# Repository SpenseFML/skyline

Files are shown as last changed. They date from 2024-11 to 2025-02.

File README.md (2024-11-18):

# Skyline
Hello everyone, 
I'm really glad that you are here, reading about my new Keyboard.
The Skyline is a 34 key wireless split keyboard with a slight angle and curved layout and agressive pinky stagger.

In total you have 4 choices what to build:
With(out) display 
With(out) hotswap sockets

If you want to mix and match, the world is your oyster, just print what you need, every version has files for both sides. Just look at the prints and pictures to see what is in your budget and what is usefull for you :)

## The whats and whys
This isn't my first self-designed keyboard and I hope it isn't my last. 
My self-build collection consists of:
Lowbro (a plancklike self printed and designed low profile)
Reviung41
Corne (with displays)
Skeletyl (self printed)
dove36 (fusion of the reviung41 and skeletyl, self designed)

The Skyline is the product of all the experiences I made building, designing and using these keyboards.
I wanted a Keyboard, that only has the number of keys (34) that I needed for my day to day work with it and it should look like something new and unique. Also I wanted to use displays in a self-built keyboard, to see how it's done and to make it more fancy :D (it looks cool, but it's not really necessary tbh)
Another important aspect for me is that I just wanted the challenge of finishing a project, that isn't just "print this file from the internet and solder some switches to a controller" and releasing it as a somewhat polished and usable product for the keyboard community to build and have fun with.

## Building the Skyline
Building your own mechanical keyboard can be a fun and very fulfilling experience. 
It can also be very demanding and hard, because you can run into problems and do mistakes, which will set you back and make you start over. 
Don't get discouraged.
Every build is a chance to learn and get better!
I wrote a [build guide](buildguide/BUILDGUIDE.md) for the Skyline with some tips and tricks to help you in the building process. If you still need help or have questions (or want to see other designs) feel free to join my [discord server](https://discord.gg/6NYX3pecrV) and just ask me directly, I'll help as much as I can :)

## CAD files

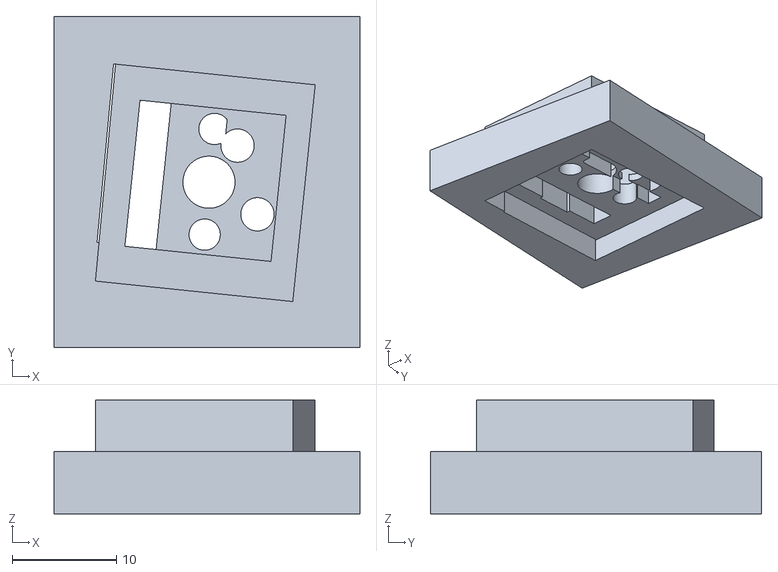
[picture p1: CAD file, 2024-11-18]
stls/print_helper.stl
29.3 x 31.8 x 10.9

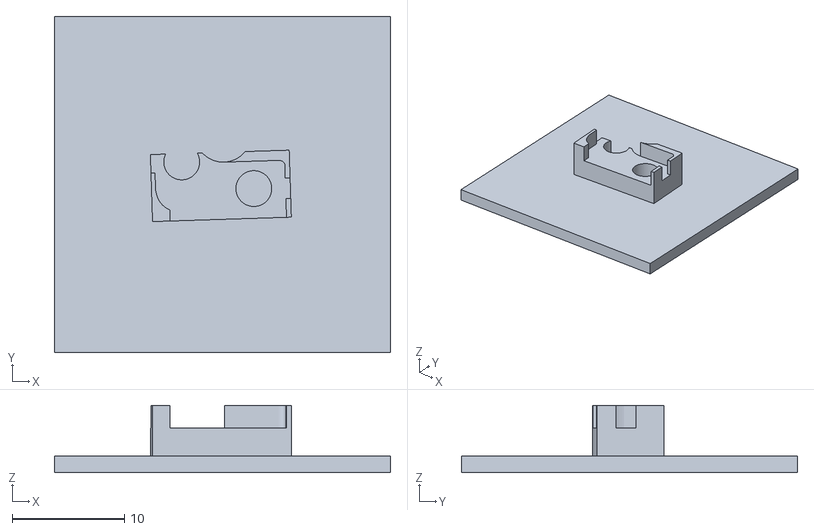
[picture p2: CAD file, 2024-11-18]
stls/hot_socket_helper.stl
30.0 x 30.0 x 6.00

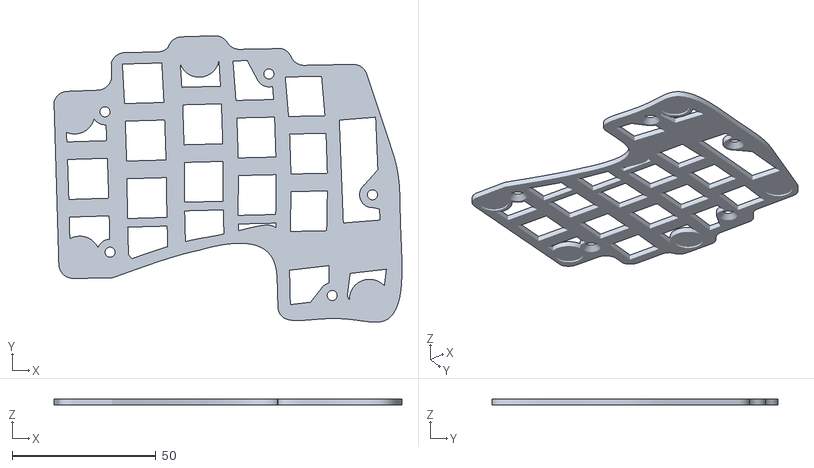
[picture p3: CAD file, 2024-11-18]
stls/plate.stl
121.0 x 99.6 x 2.00

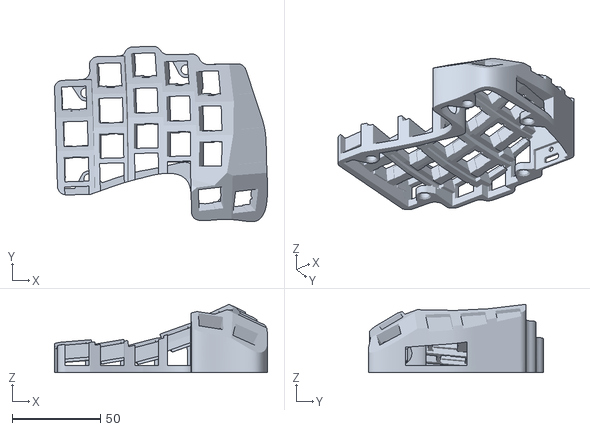
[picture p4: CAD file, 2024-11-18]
stls/case_left_no_display_no_hotswap.stl
121.0 x 99.6 x 38.9

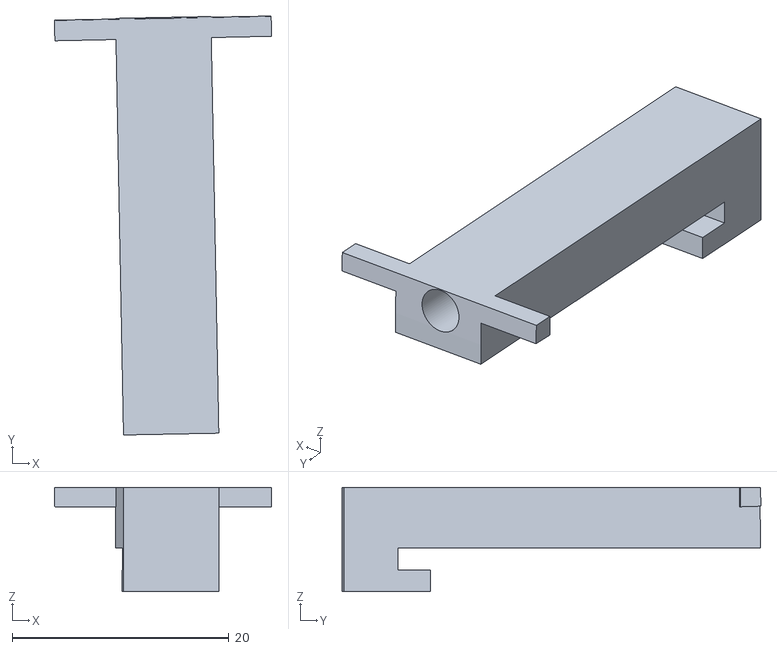
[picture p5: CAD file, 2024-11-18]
stls/controller_holder.stl
20.0 x 38.7 x 9.61

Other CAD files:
stls/case_right_display_no_hotswap.stl
stls/case_right_no_display_no_hotswap.stl
stls/case_left_display_no_hotswap.stl

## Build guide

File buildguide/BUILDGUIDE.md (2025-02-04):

# Introdution
This is the buildguide for the Skyline Keyboard.
There are different versions of the keyboard for different budgets and needs.
All costs are in € and I'm from germany, so I don't have much choice in vendors.
Some parts can be bought from aliexpress or other vendors from china, longer waittimes, but sometimes way cheaper.
**All config files in this repo are for nice nanos used with ZMK**.
If you decide on using a pro micro, or other controller, you'll have to do the config files yourself.
Also **this build requires soldering and sometimes glueing**, I don't add these costs to my estimation, because it can vary very much, depending which equipment you're using.

## Preface
All the pricings of the builds are **without your prefered choice of switches and keycaps.**
You have to add the cost of them to my estimated cost of the build.
**The cost also assumes that you print the files yourself**, keep that in mind. 
If you buy the prints the price could be 25€ to 50€ more.
**Also you will need cables, diodes, rubber anti-slip pads, screws and screw inserts.**
These will be same for every build. I compiled a list of everything you need in the [prerequisites](PREREQUISITES.md)

## The versions
**The cheapest version** you can build is with a promicro controller from an asian vendor (preferably bought in bulk) and a wired connection between both halves.
It won't look as cool as the wireless version and you are stuck with the switches you have chosen. 
You don't need batteries, "on/off" switches and you'll save a lot of time and maybe stress.
**Estimated Cost:**
**Pro Micro: 5€**

**Upgrade No.1:**
Instead of using a pro micro contoller you can use the nice nano v2.
This will allow you to fork my repo and use the ZMK config I have provided. 
For the cheaper build you can still only use one controller and wire both sides together. You'll save some money on another controller and battery, but you pay the price in looks.
**Estimated Upgrade Cost per keyboard side:**

**Nice Nano V2: 25€**

**Battery:5€**

**On/Off Switch: 3€**

**~33€ per side**

**Upgrade No.2:**
We will use hot-swap-sockets to make your choice of switches more flexible for future use. Hot-swap-sockts allow you to remove the switches from the keyboard without much hassle and insert other ones.

**This won't up the cost too much, but will make the printing and building harder**

**Estimated Upgrade Cost per keyboard side:**

**Hotswap sockets: 5€**

**Glue (I used glue for plastics, but you can use hot glue I think): 5€**

**Time: Much**

**Upgrade No.3:**
We use displays to show the battery life, connection status, layers and cool art.
**Keep in mind that you have to use 2 Nice Nanos, if you want to use 1 Display, because of the limited pins on the controller**
I used the nice view displays, you can use other displays that fit.

**Estimated Upgrade Cost per keyboard side:**
**Nice View Display: 25€**

## What now?
Now you have to choose what you want to build. 
Print what you have chosen and go to building.
As mentioned in the [prerequisites](PREREQUISITES.md) I'd recommend to print the [print helper](../stls/print_helper.stl) first to check your settings and test if everything works the way you want it to.

### Preparing while printing

For the next step it depends if you use hot-swap-sockets or not.

**With hot-swap-sockets**
I added a [stl file](../stls/hot_socket_helper.stl) that you can print, which helps you soldering the hot-swap sockets to the diodes. Just insert the hot-swap-socket into the frame.
Now you have to solder the diode. Prepare it like [this] and solder it to the right side of the hot-swap-socket like [this] (the arrow shows the side where the diode has to be soldered on).
**Be sure that every Diode has the same orientation**
Do that with every socket you have (so 34 times)
For the other side you need easily bendable wire like the one on the diodes. If you have enough of them, so you can sacrifice some, you can just clip it off the wire on the diodes and use it. You can also buy wire like [this] if you don't want to destroy your diodes.
Solder it like this. 
When you're done you have to wait for your prints to finish.

**Without hot-swap-sockets**
Prepare the diodes like [this].
We will solder them directly on the switch and we do it, when the switch is already in the case, so we have to wait on the prints to finish.

### When the prints are ready

#### Test the prints
First off you should put every switch in to see if the print was successful. Do the same with the prepared hot-swap-sockets. Test if the sockets fit in with the switch. 
If they don't you can try to fix the print with a blade or clipper. If you can't solve the problem, please let me know, so I know that my file has an error, or we can look over your printing settings. 

#### Start with the screw inserts
Nothing is more annoying then soldering the board, seeing that everything works and then screwing up the screw inserts. Now you have a functional board without plates on the bottom, a rather unfortunate situation.
Do yourself a favor and start with putting in the screwinserts. Just put them on your soldering iron and slowly push them into the holes. 
**Test every screw insert and try to put the plates on before you start soldering the rest.**

#### Glue the hot-swap-sockets
When you're sure that everything fits and works you can glue in the hot-swap-sockets. This process takes some time, because the sockets should be atleast a little bit dried before you start soldering. Wait an appropriate time, depending on the glue you used. 
When you have waited enough you can begin to solder.

#### Soldering the components
We will be soldering a Matrix. This means, that we wont connect every single switch to the controller, but connect them in columns and rows to reduce the pins we need on the controller. You can read more about how and why we do switch matrix [here](https://www.crackedthecode.co/a-complete-guide-to-building-a-hand-wired-keyboard/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
).

BTW: You don't have to do the soldering like I do in this guide, you're free to do it the way you like. I just found my pretty easy for soldering the sockets without too much measuring and still keeping it clean.

**With hot-swap-sockets**

Now solder the Diodes together and try to stuff them in the [cutout] I have prepared for them. These are our Columns.
Now solder together the rows. Just connect every Socket like [this]. 

**Without hot-swap-sockets**

Put the diodes on the right side of the switch and solder them to the switch. 
Solder the diodes together, now we have our [Columns].
After that solder the [Rows] of the switches together.

**Connect everything to the Controller**

Now that we have our Rows and Columns together we have to connect them to the controller. [Here's] a picture of the pinout of the nice nano. I marked which col and row have to be connected to which pin. When you do it like this, you can use my config right off the bat. You can make changes how you prefere, but have to change the mapping in the overlay file.

We use insulated wires for this step, so we don't run into short circuts. 

**If you use Batteries**

After that you can solder the batteries. You will have to connect one wire of the battery to the controller and the other to the on/off switch. Then connect the on/off switch to the controller.

**If you use the display**

Solder 5 insulated wires to the pins of the display. Put the display in place and solder the wires to the controller. 

**Testing your build**
You can flash the firmware on the controller and see if the displays work.
You can test every switch and the on/off switch too. 
Glue the display to the case and fix the on/off switch if everything works.
Be sure to wait the appropriate amount of time for your glue too harden before you insert the switches.

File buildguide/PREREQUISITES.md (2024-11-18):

## Prerequisits
First and foremost
**If you don't know how to solder, it's best to watch a tutorial on youtube beforehand, so you don't damage the controller or switches.**

Here is a list of everything you need, no matter which version you chose:

1x Soldering Iron with attachment

1x Your choice of solder

1x Your choice of flux (not needed, but recommended for easier soldering)

10x M4 Screw inserts (3-4mm long)

10x M4 Flat headed Screws (at least 7mm long in total)

2x M2 Screw inserts (3-7mm long)

2x M2 Round head Screws (at least 7mm long in total)

1x Screwdriver for your chosen screws

10x anti-slip rubber pads (max 9mm diameter, if printer settings are really good 10mm could work too)

34x 1N4148 Diode (I'd recommend more, if you make a mistake)

1 meter of cable (it's probably way less, but just to be sure)

1x Den wire ersatz denn ich noch erfrage

1x pliers to cut the cable

This should be every basic component you need to start your Skyline journey. 

## If you're printing the case yourself
I added [this]() file to help you find the right printer settings. You can test the support here and if your glue works for the hot-swap-sockets, how long you have to wait and if you can insert a switch afterwards.
**I recommend to print this first to see if everything will work in the end!**

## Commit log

2024-11-18 added stls
    [case_left_display_no_hotswap.stl, case_left_no_display_no_hotswap.stl, case_right_display_no_hotswap.stl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]
2024-11-18 Added more files. Build guide topics done
    [hot_socket_helper.stl, print_helper.stl]
